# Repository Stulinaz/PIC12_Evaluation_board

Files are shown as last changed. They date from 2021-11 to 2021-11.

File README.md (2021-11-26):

# PIC12_Evaluation_board
kicad project of my custom PIC12 evaluation board

I'm Enrico and i am FCT board tester. I designed this board for rapid design of 8 pin microcontroller application that support my work.

The pic 12 board include:

-PICKIT connector on board.

-Large build area.

-Double Power supply from usb connector or from CR2032 battery for portable applications.

-Supports pullup and pulldown resistors for every pin.

-BOM is displayed on bottom silkscreen side.

TOP SIDE:

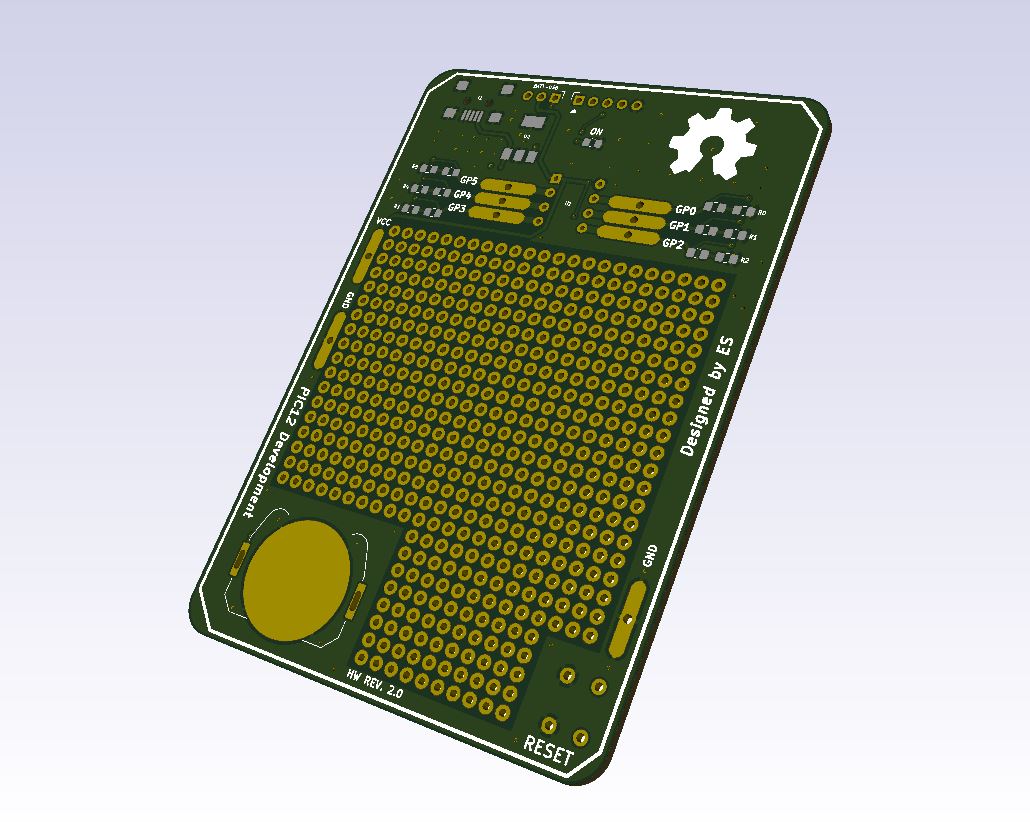
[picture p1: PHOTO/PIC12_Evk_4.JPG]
Test Image 1


BOTTOM SIDE:

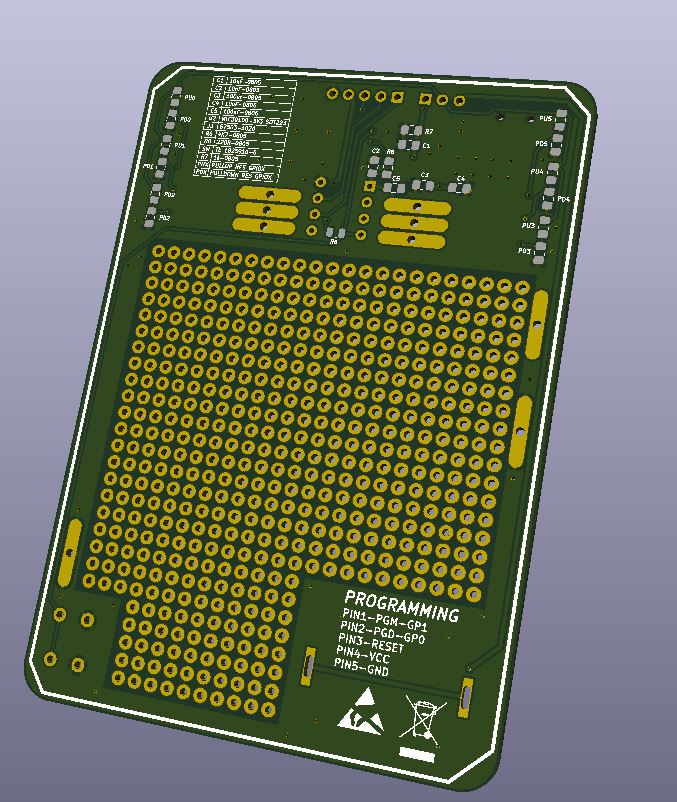
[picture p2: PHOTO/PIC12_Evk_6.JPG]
Test Image 2


ASSEMBLED PCB:

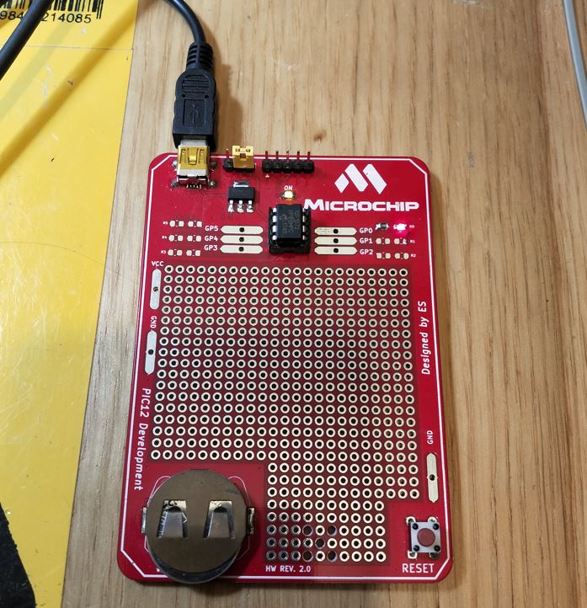
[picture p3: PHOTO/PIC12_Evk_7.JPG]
Test Image 3


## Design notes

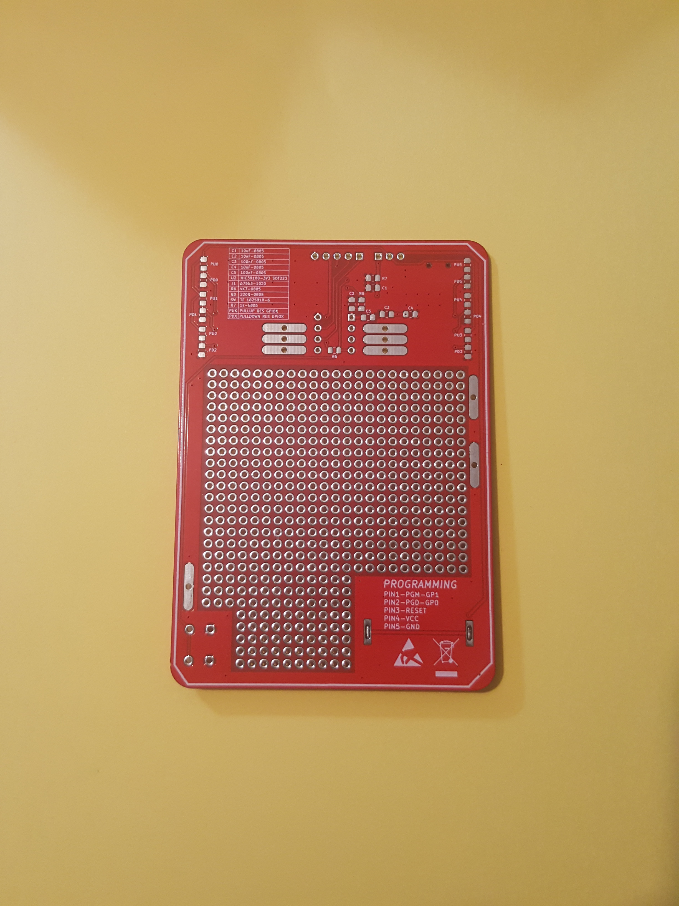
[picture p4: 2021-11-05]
PHOTO/PIC12_Evk_2.jpg

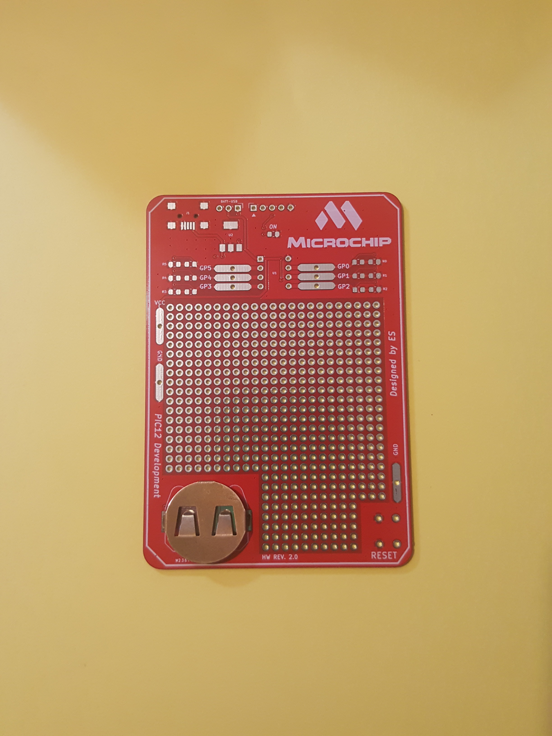
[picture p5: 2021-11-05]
PHOTO/PIC12_Evk_1.jpg

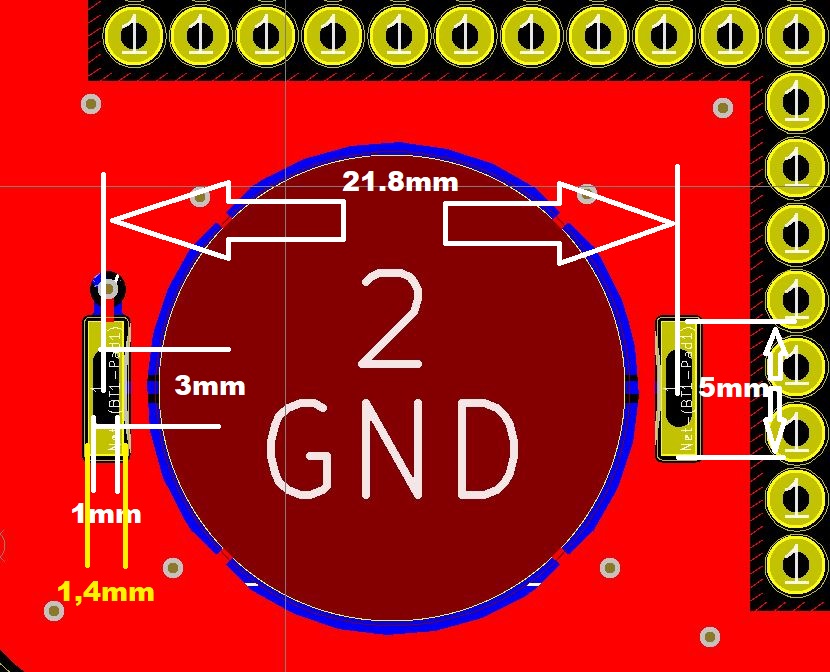
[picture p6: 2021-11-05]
PHOTO/PIC12_Evk_3.JPG

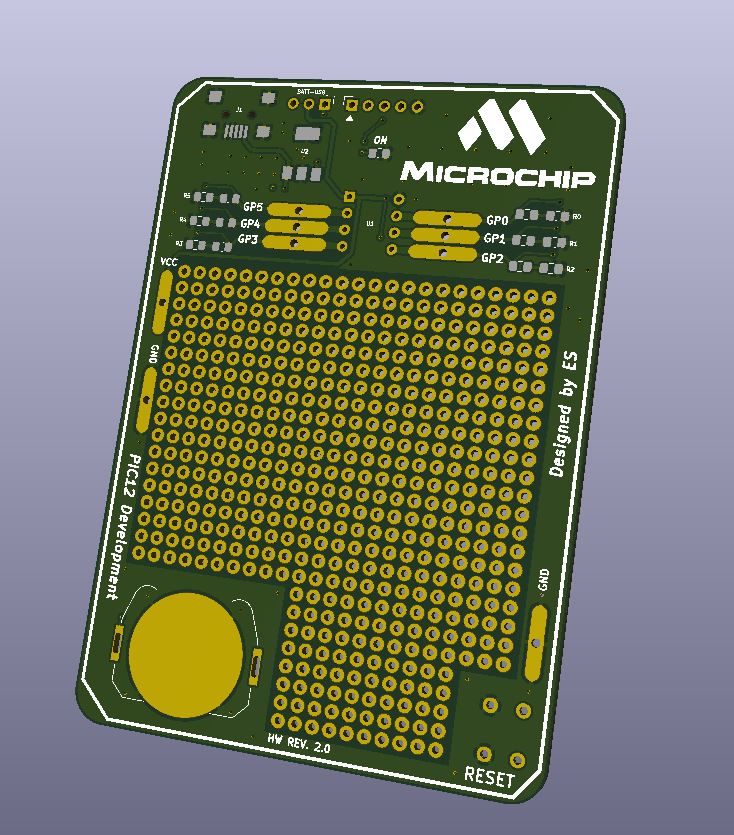
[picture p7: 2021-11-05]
PHOTO/PIC12_Evk_5.JPG

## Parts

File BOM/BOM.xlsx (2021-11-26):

COMPONENT | PART NUMBER | DESCRIPTION | QTY | DIGIKEY ORDER CODE
U2 | MIC39100-3.3WS | Linear Voltage Regulator IC Positive Fixed 1 Output 1A SOT-223-3 | 1 | 576-1172-ND
U1 | PIC12F675-I/P | IC MCU 8BIT 1.75KB FLASH 8DIP | 1 | PIC12F675-I/P-ND
BT1 | 3034 | BATT RETAINER COIN 20MM 1CEL SMD | 1 | 36-3034-ND
R0,R1,R2,R3,R4,R5,R8 | RMCF0805JT1K00 | RES 1k OHM 5% 1/8W 0805 | 7 | RMCF0805JT1K00CT-ND
LED_ON1 | LG R971-KN-1 | LED GREEN DIFFUSED 0805 SMD | 1 | 475-1410-1-ND
RESET1 | 1825910-7 | SWITCH TACTILE SPST-NO 0.05A 24V | 1 | 450-1804-ND
C4, C5 | C0805C101K8RAC7800 | CAP CER 100PF 10V X7R 0805 | 2 | 399-15004-1-ND
C1, C2, C3 | C0805C106K4PAC7800 | CAP CER 10UF 16V X5R 0805 | 3 | 399-C0805C106K4PAC7800CT-ND
PD0,PD1,PD2,PD3,PD4,PD5,PU0,PU1,PU2,PU3,PU4,PU5, R6 | CR0805-JW-103ELF | RES SMD 10k OHM 5% 1/W 0805 | 13 | CR0805-JW-103ELFCT-ND
PU0,PU1,PU2,PU3,PU4,PU5 | CR0805-JW-103ELF | RES SMD 10k OHM 5% 1/W 0805 | 6 | CR0805-JW-103ELFCT-ND
CONNECTOR PROG1,CONNECTOR SWITCH1 | 1-87220-0 | CONN HEADER VERT 10POS 2.54MM | 2 | A26556-ND

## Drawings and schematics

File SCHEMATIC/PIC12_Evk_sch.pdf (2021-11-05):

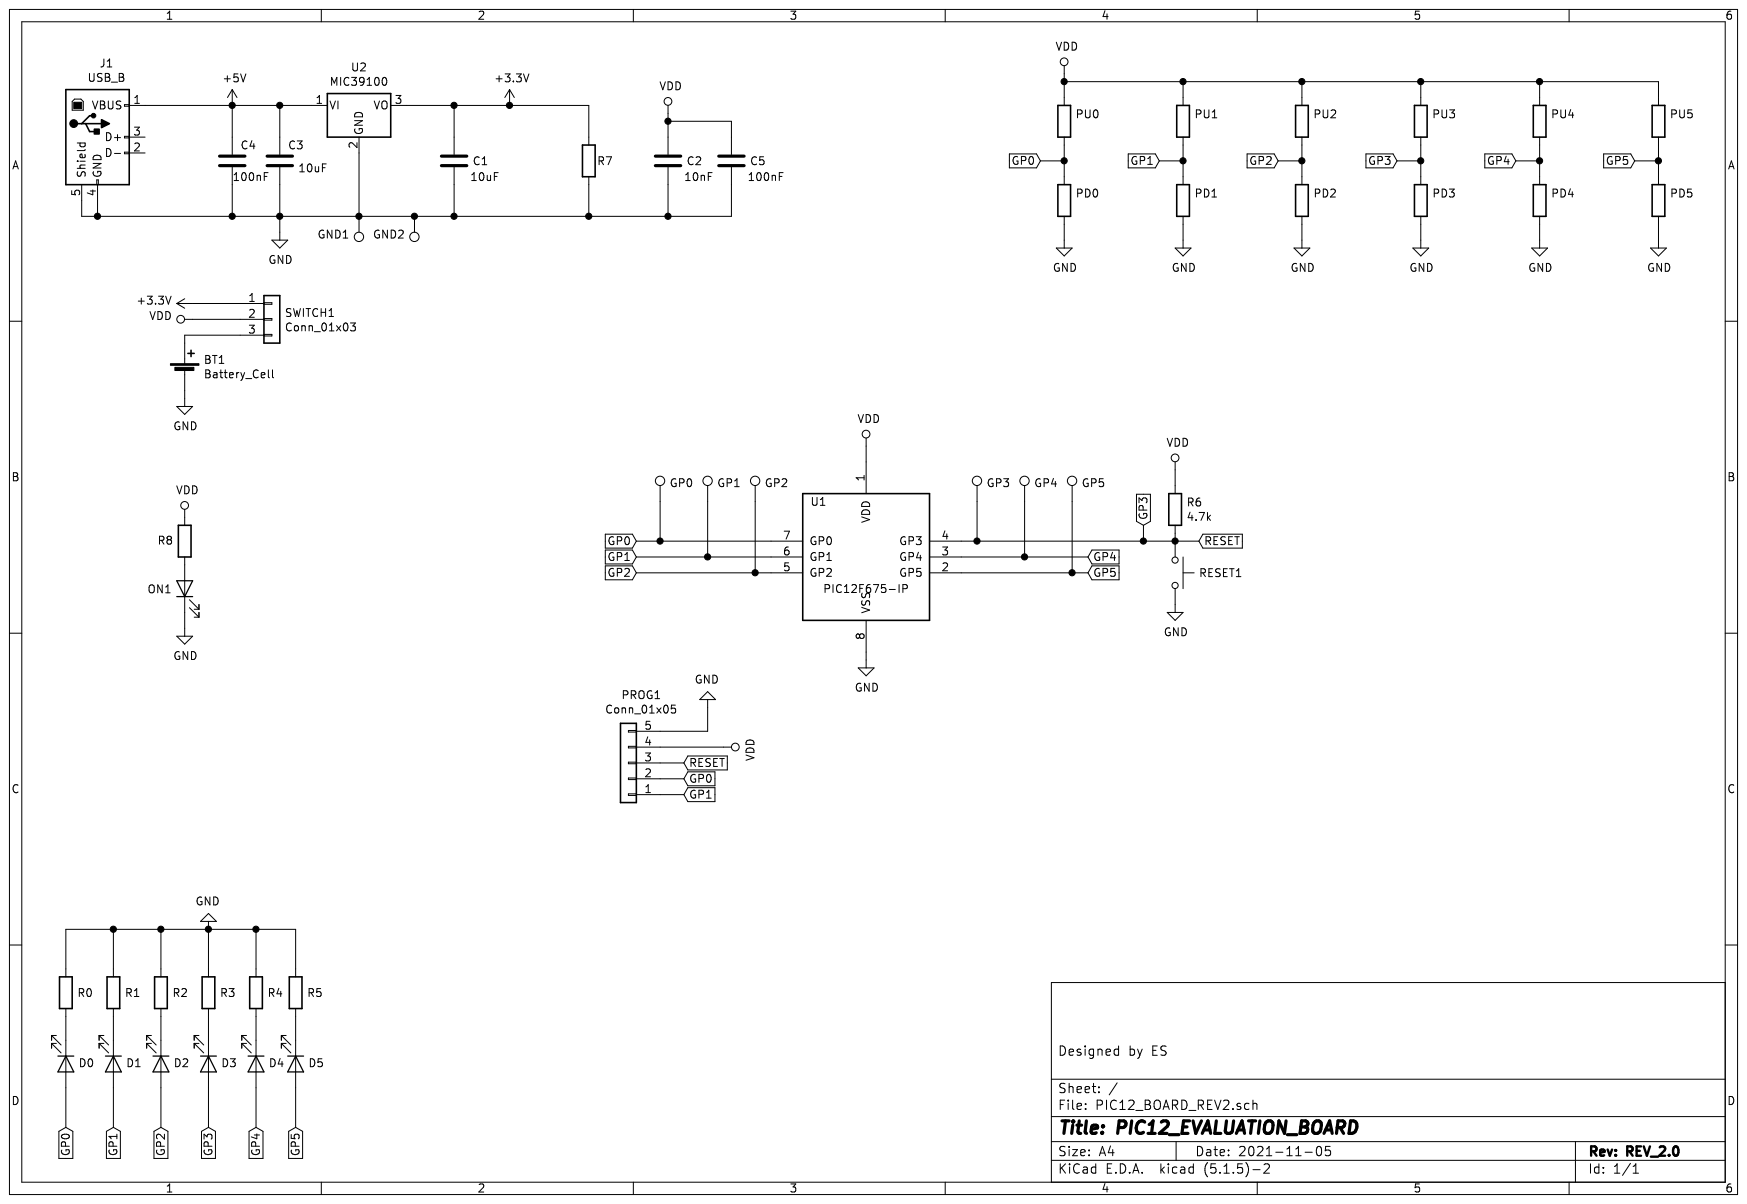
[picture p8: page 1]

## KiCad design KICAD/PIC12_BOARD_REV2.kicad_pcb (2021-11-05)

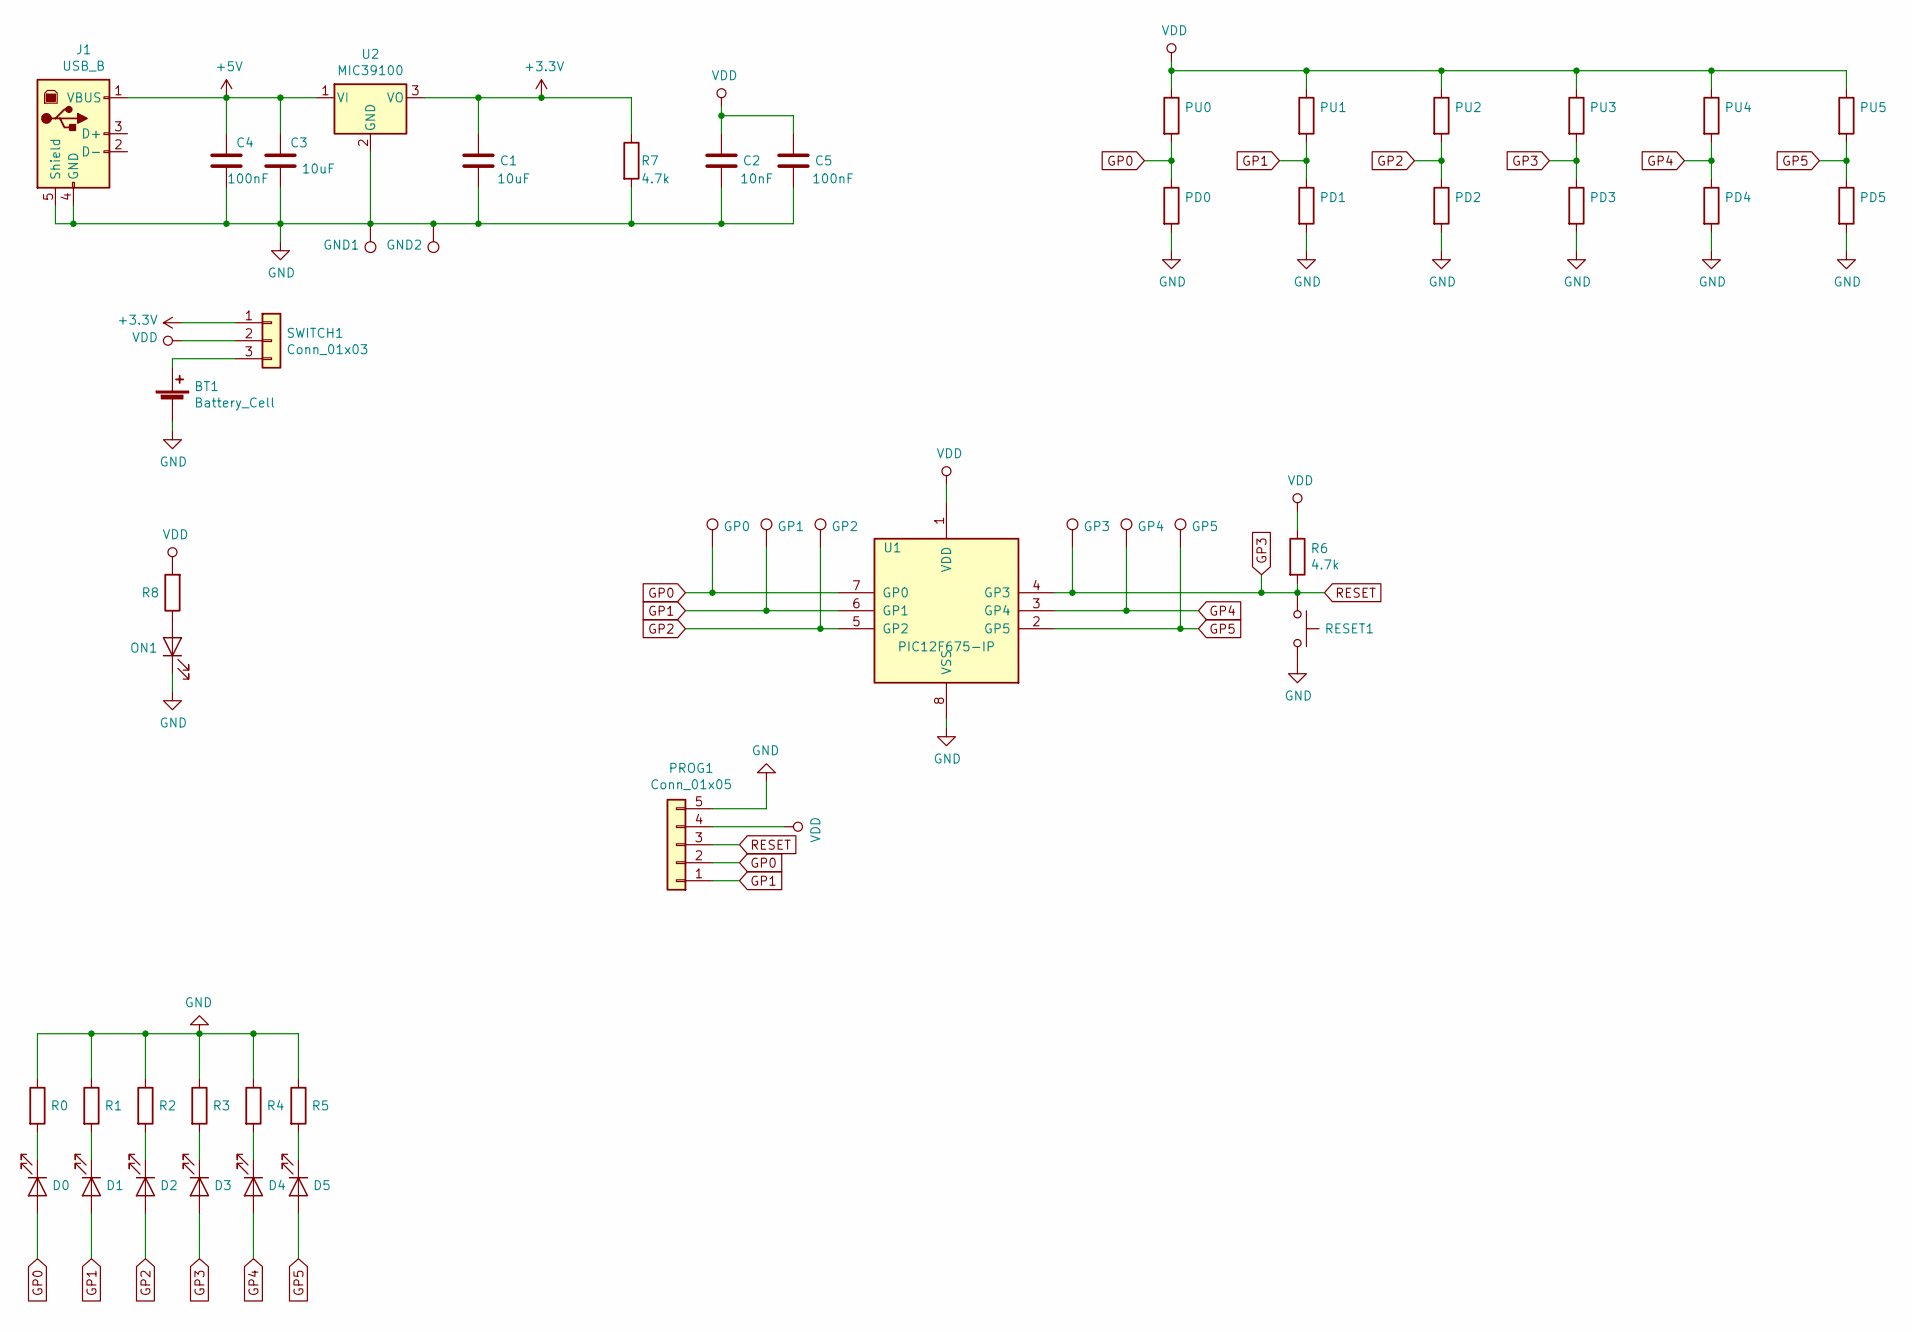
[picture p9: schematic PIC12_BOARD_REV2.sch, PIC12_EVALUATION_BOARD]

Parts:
BT1: Battery_Cell; BatteryHolder_Keystone_3034_1x20mm
C1, C3: 10uF; R_0805_2012Metric_Pad1.15x1.40mm_HandSolder
C2: 10nF; R_0805_2012Metric_Pad1.15x1.40mm_HandSolder
C4, C5: 100nF; R_0805_2012Metric_Pad1.15x1.40mm_HandSolder
D0, D1, D2, D3, D4, D5: LED; R_0805_2012Metric_Pad1.15x1.40mm_HandSolder
GND1, GND2: TestPoint; TP_EN0
GP0, GP1, GP2, GP3, GP4, GP5: TestPoint; TP_EN0
J1: USB_B; USB_Mini-B_Lumberg_2486_01_Horizontal
ON1: LED; R_0805_2012Metric_Pad1.15x1.40mm_HandSolder
PD0, PD1, PD2, PD3, PD4, PD5: 4.7k; R_0805_2012Metric_Pad1.15x1.40mm_HandSolder
PROG1: Conn_01x05; PinSocket_1x05_P2.54mm_Vertical
PU0, PU1, PU2, PU3, PU4, PU5: 4.7k; R_0805_2012Metric_Pad1.15x1.40mm_HandSolder
R0, R1, R2, R3, R4, R5: R; R_0805_2012Metric_Pad1.15x1.40mm_HandSolder
R6: 4.7k; R_0805_2012Metric
R7: 4.7k; R_0805_2012Metric_Pad1.15x1.40mm_HandSolder
R8: 220; R_0805_2012Metric_Pad1.15x1.40mm_HandSolder
RESET1: SW_Push; SW_PUSH_6mm
SWITCH1: Conn_01x03; PinHeader_1x03_P2.54mm_Vertical
U1: PIC12F675-IP; DIP-8_W7.62mm
U2: MIC39100; SOT-223-3_TabPin2

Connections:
+3V3: C1.1, R7.1, SWITCH1.1, U2.3 (VO)
+5V: C3.1, C4.1, J1.1 (VBUS), U2.1 (VI)
DATA+: J1.3 (D+)
DATA-: J1.2 (D-)
GND: BT1.2 (-), C1.2, C2.2, C3.2, C4.2, C5.2, GND1.1, GND2.1, J1.4 (GND), J1.5 (Shield), J1.6, ON1.1 (K), PD0.2, PD1.2, PD2.2, PD3.2, PD4.2, PD5.2, PROG1.5, R0.1, R1.1, R2.1, R3.1, R4.1, R5.1, R7.2, RESET1.2, U1.8 (VSS), U2.2 (GND)
GP0: D0.2 (A), GP0.1, PD0.1, PROG1.2, PU0.2, U1.7 (GP0)
GP1: D1.2 (A), GP1.1, PD1.1, PROG1.1, PU1.2, U1.6 (GP1)
GP2: D2.2 (A), GP2.1, PD2.1, PU2.2, U1.5 (GP2)
GP3: D3.2 (A), GP3.1, PD3.1, PROG1.3, PU3.2, R6.2, RESET1.1, U1.4 (GP3)
GP4: D4.2 (A), GP4.1, PD4.1, PU4.2, U1.3 (GP4)
GP5: D5.2 (A), GP5.1, PD5.1, PU5.2, U1.2 (GP5)
unnamed: BT1.1 (+), SWITCH1.3
unnamed: D0.1 (K), R0.2
unnamed: D1.1 (K), R1.2
unnamed: D2.1 (K), R2.2
unnamed: D3.1 (K), R3.2
unnamed: D4.1 (K), R4.2
unnamed: D5.1 (K), R5.2
unnamed: ON1.2 (A), R8.1
VDD: C2.1, C5.1, PROG1.4, PU0.1, PU1.1, PU2.1, PU3.1, PU4.1, PU5.1, R6.1, R8.2, SWITCH1.2, U1.1 (VDD); also elsewhere on the board

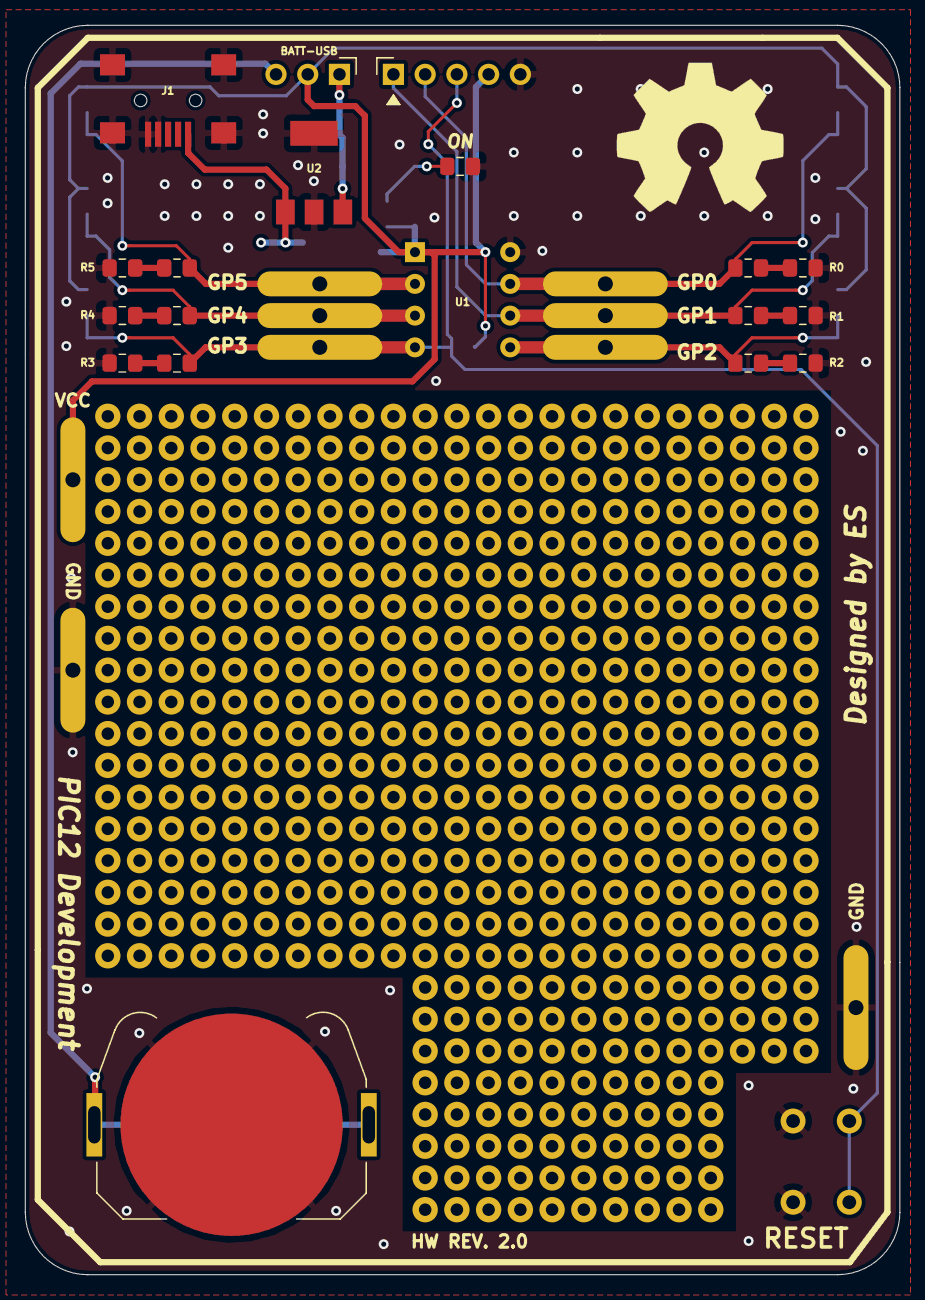
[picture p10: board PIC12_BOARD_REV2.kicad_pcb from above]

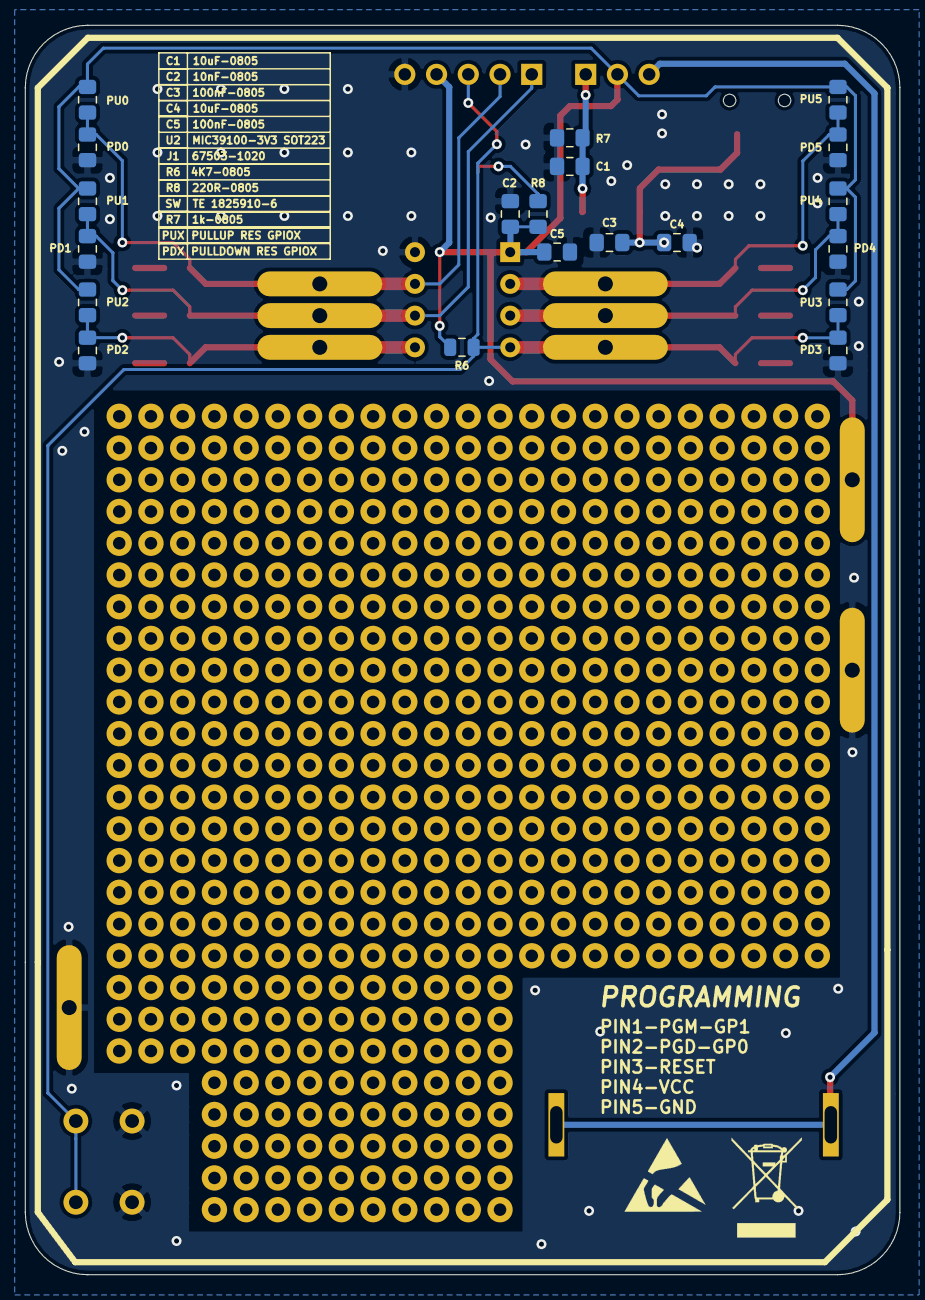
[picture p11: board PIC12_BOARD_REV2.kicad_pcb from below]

Board: 2 copper layers, 70.0 x 100.0 mm, 49 parts (20 on the bottom side), 18 nets.

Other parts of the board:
VCC1: TestPoint; TP_EN0

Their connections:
VDD: VCC1.1; also elsewhere on the board
